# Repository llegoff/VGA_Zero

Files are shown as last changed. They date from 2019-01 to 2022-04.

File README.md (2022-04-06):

[:fr:](LISEZMOI.md) [:uk:](README.md)

# VGA_Zero
VGA interface for Raspberry Pi Zéro &amp; 2,3,B+

for pi400 see https://github.com/llegoff/Pi400VGA

buy rev3 on [ebay](https://www.ebay.fr/itm/154857982971) :package:

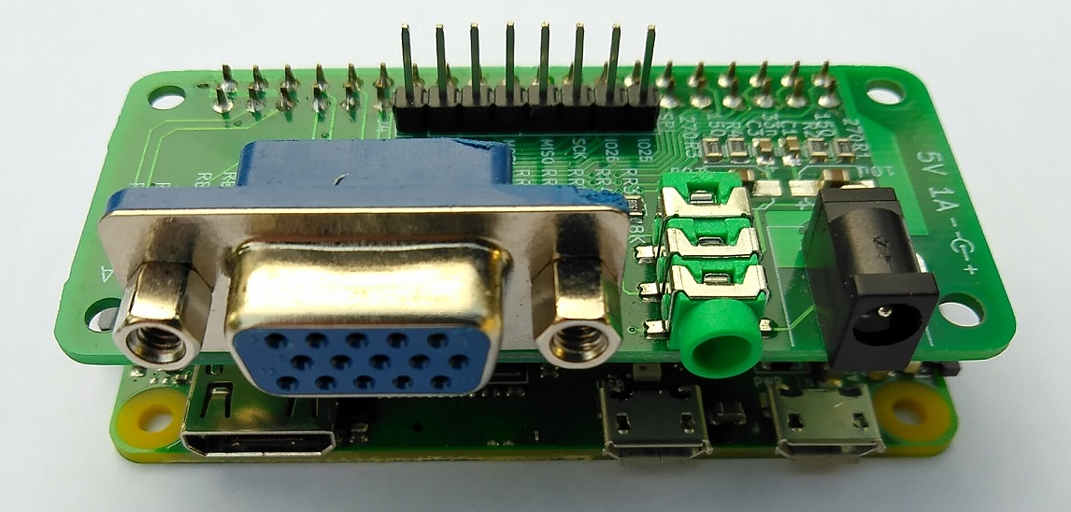
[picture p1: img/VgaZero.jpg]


### DPI (Display parallel Interface)
Like [VGA666](https://github.com/fenlogic/vga666), this pcb uses dpi interface (in mode 3 to free gpio 18 & 19)

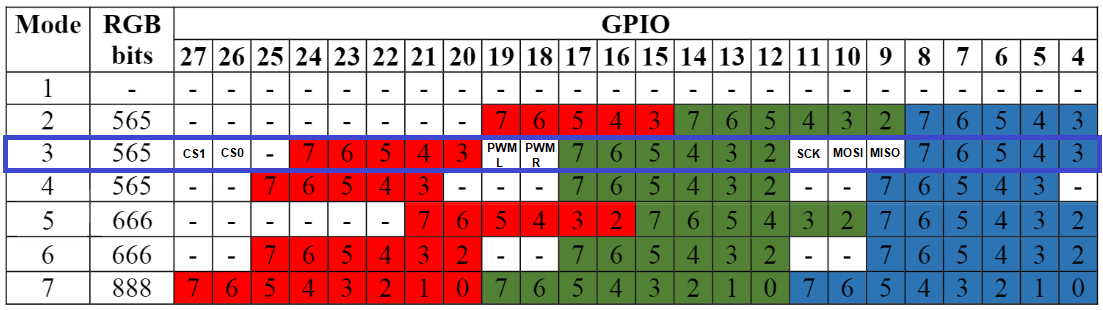
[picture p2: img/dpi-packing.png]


see https://www.raspberrypi.org/documentation/hardware/raspberrypi/dpi/README.md

only the necessary bits of the dpi are redirected to the 40-pin GPIO port, with the [vga565.dtbo](overlays/vga565.dtbo?raw=true) file loaded at startup

here is the code of the file:

    /dts-v1/;
    /plugin/;
    /{
    	compatible = "brcm,bcm2708";
    	// There is no VGA driver module, but we need a platform device
    	// node (that doesn't already use pinctrl) to hang the pinctrl
    	// reference on - leds will do
    	fragment@0 {
    		target = <&leds>;
    		__overlay__ {
    			pinctrl-names = "default";
    			pinctrl-0 = <&vga565_pins>;
    		};
	    };
    	fragment@1 {
    		target = <&gpio>;
    		__overlay__ {
    			vga565_pins: vga565_pins {
        			brcm,pins = <2 3 4 5 6 7 8 12 13 14 15 16 17 20 21 22 23 24>;
    				brcm,function = <6>; /* alt2 */
				    brcm,pull = <0>; /* no pull */
			    };
		    };
	    };
    };

/boot/config.txt
    
    # disable i2c, pin use by h-sync & v-sync
    dtparam=i2c_arm=off
    dtoverlay=vga565
    dpi_output_format=0x13
    enable_dpi_lcd=1
    display_default_lcd=1
    dpi_group=2
    dpi_mode=16
    #---------------- dpi_mode line ---------------------
    #---> 640x480 60hz    dpi_mode=4
    #---> 800x600 60hz    dpi_mode=9
    #---> 1024x768 60hz   dpi_mode=16
    #---> 1280x768 60hz   dpi_mode=23
    #---> 1280x800 60hz   dpi_mode=28
    #---> 1280x960 60hz   dpi_mode=32
    #---> 1280x1024 60hz  dpi_mode=35
    #---> 1360x768 60hz   dpi_mode=39
    #---> 1366x768 60hz   dpi_mode=81
    #---> 1400x1050 60hz  dpi_mode=42
    #---> 1440x900 60hz   dpi_mode=47
    #---> 1600x1200 60hz  dpi_mode=51
    #---> 1680x1050 60hz  dpi_mode=58
    #---> 1920x1080 60hz  dpi_mode=82
    #---> 1920x1200 60hz  dpi_mode=69
    #---> 1920x1440 60hz  dpi_mode=73

alternate config, no need dtbo file

    # replace dtoverlay=vc4-kms-v3d with
    dtoverlay=vc4-fkms-v3d
    # disable i2c, pin use by h-sync & v-sync
    dtparam=i2c_arm=off
    gpio=2-8,12-17,20-24=a2
    dpi_output_format=0x13
    enable_dpi_lcd=1
    display_default_lcd=1
    dpi_group=2
    dpi_mode=16
    #---------------- dpi_mode line ---------------------
    #---> 640x480 60hz    dpi_mode=4
    #---> 800x600 60hz    dpi_mode=9
    #---> 1024x768 60hz   dpi_mode=16
    #---> 1280x768 60hz   dpi_mode=23
    #---> 1280x800 60hz   dpi_mode=28
    #---> 1280x960 60hz   dpi_mode=32
    #---> 1280x1024 60hz  dpi_mode=35
    #---> 1360x768 60hz   dpi_mode=39
    #---> 1366x768 60hz   dpi_mode=81
    #---> 1400x1050 60hz  dpi_mode=42
    #---> 1440x900 60hz   dpi_mode=47
    #---> 1600x1200 60hz  dpi_mode=51
    #---> 1680x1050 60hz  dpi_mode=58
    #---> 1920x1080 60hz  dpi_mode=82
    #---> 1920x1200 60hz  dpi_mode=69
    #---> 1920x1440 60hz  dpi_mode=73

Configuration working with vc4-kms-v3d

    dtoverlay=vc4-kms-dpi-generic,rgb565-padhi
    dtparam=hactive=800,hfp=40,hsync=128,hbp=88
    dtparam=vactive=600,vfp=1,vsync=4,vbp=23
    dtparam=clock-frequency=40000000
    #   Resolution@freq  hactive hfp hsync  hbp vactive vfp vsync vbp  clock-frequency
    #VGA   640x480  @60   640     16   96    48   480    10   2    33    25175000
    #SVGA  800x600  @60   800     40  128    88   600     1   4    23    40000000
    #XGA  1024x768  @60  1024     24  136   160   768     3   6    29    65000000
    #VESA 1368x768  @60  1368     72  144   216   768     1   3    23    85860000
    #VESA 1280x800  @60  1280     64  136   200   800     1   3    24    83460000
    #VESA 1280x1024 @60  1280     48  112   248  1024     1   3    38   108000000
    #VESA 1400x1050 @60  1400     88  152   240  1050     1   3    33   122660000
    #VESA 1600x1200 @60  1600     64  192   304  1200     1   3    46   162000000
    #--- TV -----
    #244p (NTSC res)@60   320      4   30    46   240     4   5    14     6400000
    #288p (PAL res) @50   384     16   32    40   288     3   2    19     7363200
    #480i (NTSC res)@60   640     24   64   104   480     3   6    34    13054080
    #576i (PAL res) @50   768     24   72    88   576     6   5    38    14875000
    #480p           @60   640     24   96    48   480    11   2    32    25452000
    #720p           @60  1280    110   40   220   720     5   5    20    74250000
    #1080p          @60  1920     88   44   148  1080     4   5    36   148500000
    #more timming on http://tinyvga.com/vga-timing

### 15khz cathode ray screen

    # disable i2c, pin use by h-sync & v-sync
    dtparam=i2c_arm=off
    gpio=2-8,12-17,20-24=a2
    dpi_output_format=0x13
    enable_dpi_lcd=1
    display_default_lcd=1
    dpi_group=2
    dpi_mode=87
    #hdmi_timings=506 1 8 48 56 240 1 3 10 6 0 0 0 60 0 9600000 1
    #hdmi_timings=512 1 16 48 64 288 1 3 5 6 0 0 0 50 0 9600000 1
    # Custom 15kHz mode
    hdmi_timings=506 1 8 44 52 240 1 6 10 6 0 0 0 60 0 9600000 1
    #hdmi_timings=320 1 17 33 34 224 1 14 8 18 0 0 0 60 0 6400000 1
    #hdmi_timings=960 0 173 8 0 160 0 40 10 0 0 0 0 60 0 19200000 8
    #hdmi_timings=320 1 25 30 30 240 1 9 3 10 0 0 0 60 0 6400000 1
    #hdmi_timings=1920 1 52 208 260 240 1 6 10 6 0 0 0 60 0 38400000 1
    
for recalbox see https://recalbox.gitbook.io/tutorials/v/francais/video/crt/configurez-votre-ecran-cathodique-sur-le-bus-dpi-vga666-piscart-rgbpi

### Dual Screen (VGA + HDMI)

on the pi4 and pi400, the dual screen function is supported by the vc4 fkms v3d driver

    [pi4]
    # Enable DRM VC4 V3D driver on top of the dispmanx display stack
    dtoverlay=vc4-fkms-v3d
    max_framebuffers=2
    
for previous versions:

:warning: need raspbian buster

edit file /boot/config.txt  

at the end of the file, add line:

    [all]
    #dtoverlay=vc4-fkms-v3d
    max_framebuffers=2

edit file /usr/share/X11/xorg.conf.d/99-fbturbo.conf

     This is a minimal sample config file, which can be copied to
    # /etc/X11/xorg.conf in order to make the Xorg server pick up
    # and load xf86-video-fbturbo driver installed in the system.    
    #
    # When troubleshooting, check /var/log/Xorg.0.log for the debugging
    # output and error messages.
    #
    # Run "man fbturbo" to get additional information about the extra
    # configuration options for tuning the driver.
    
    #Section "Device"
    #        Identifier      "Allwinner A10/A13 FBDEV"
    #        Driver          "fbturbo"
    #        Option          "fbdev" "/dev/fb0"
    #        Option          "SwapbuffersWait" "true"
    #EndSection
    
    Section "Device"
    Identifier "Raspberry Pi HDMI"
    Driver "fbturbo"
    Option "fbdev" "/dev/fb0"
    Option "ShadowFB" "off"
    EndSection
    
    Section "Device"
    Identifier "Raspberry Pi DPI"
    Driver "fbturbo"
    Option "fbdev" "/dev/fb1"
    Option "ShadowFB" "off"
    EndSection
    
    Section "Monitor"
    Identifier "HDMI"
    EndSection

    Section "Monitor"
    Identifier "DPI"
    EndSection
    
    Section "Screen"
    Identifier "screen0"
    Device "Raspberry Pi HDMI"
    Monitor "HDMI"
    EndSection
    
    Section "Screen"
    Identifier "screen1"
    Device "Raspberry Pi DPI"
    Monitor "DPI"
    EndSection
    
    Section "ServerLayout"
    Identifier "default"
    Screen 0 "screen0" 0 0
    Screen 1 "screen1" RightOf "screen0"
    Option "Xinerama" "on"
    EndSection
### Remote Desktop MultiMonitor
install freeRDP

    sudo apt-get install freerdp2-x11

start freeRDP session
    
    xfreerdp /v:<computer name or IP> /u:<user> /d:<domain> /sound:sys:alsa /multimon

or

    xfreerdp /v:<computer name or IP> /u:<user> /d:<domain> /g:<gateway name or IP> /gu:<gateway user> /gd:<gateway domain> /sound:sys:alsa /multimon

### Audio Interface
audio interface is connected to gpio 18 & 19 (PWM)

see https://learn.adafruit.com/adding-basic-audio-ouput-to-raspberry-pi-zero/pi-zero-pwm-audio

/boot/config.txt

    # Enable audio for PiZero(loads snd_bcm2835)
    dtoverlay=pwm-2chan,pin=18,func=2,pin2=19,func2=2
    dtparam=audio=on

For Pi4 or Pi400 use audremap overlay

/boot/config.txt

    # Enable audio for PiZero(loads snd_bcm2835)
    dtoverlay=audremap,pins_18_19
    dtparam=audio=on

### SPI Interface
GPIO 9 , 10, 11 , 25, 26, 27 can be used as SPI , whit overlay spi0-cs, with CS redirection to gpio 26 & 27

/boot/config.txt

    # uncomment to use spi0 with cs0 & cs1 retirected on pin 26 & 27 
    dtparam=spi=on
    dtoverlay=spi0-cs,cs0_pin=26,cs1_pin=27

## Schematic
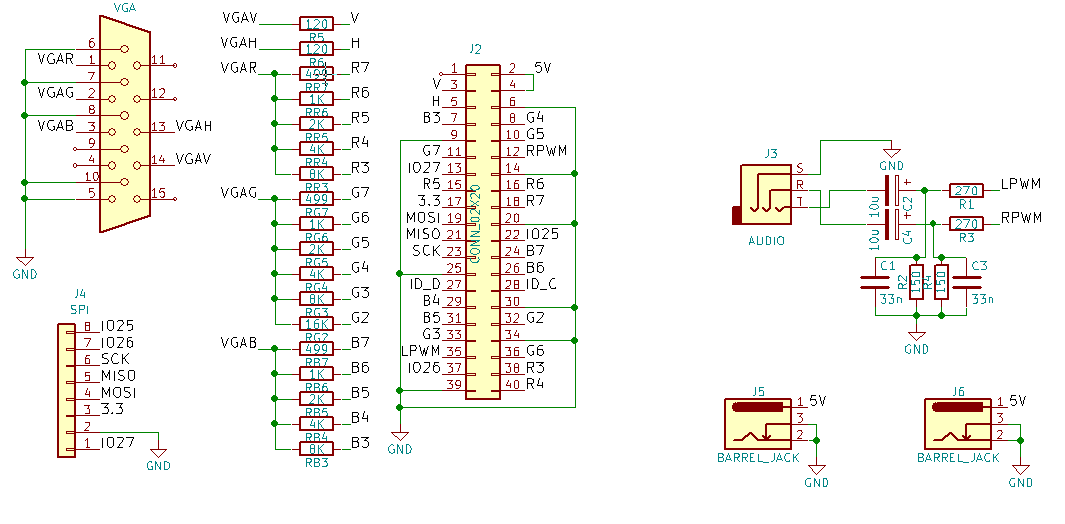
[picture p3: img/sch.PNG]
sch


## PCB
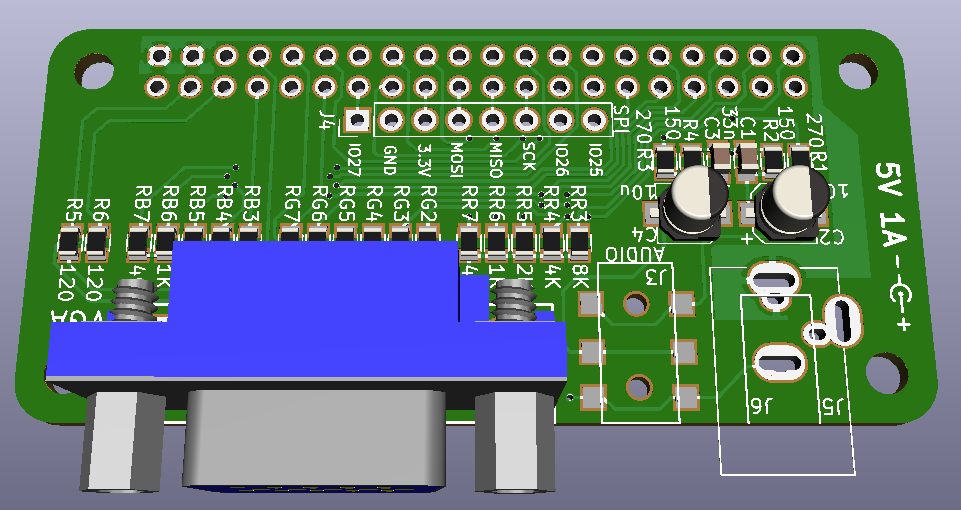
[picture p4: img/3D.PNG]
pcb


## Installation
Copy [vga565.dtbo](overlays/vga565.dtbo?raw=true) to /boot/overlays/
and copy content of [config-example.txt](overlays/config-example.txt?raw=true) to /boot/config.txt

## Révision
rev1
- bad vga footprint, hole too small

rev2
- change vga footprint
- move j3 & j5

rev3
- add GPIO25 to J4 connector
- add j6 DC 3.5x1.3 connector
- change to Kicad v5.0.2 lib

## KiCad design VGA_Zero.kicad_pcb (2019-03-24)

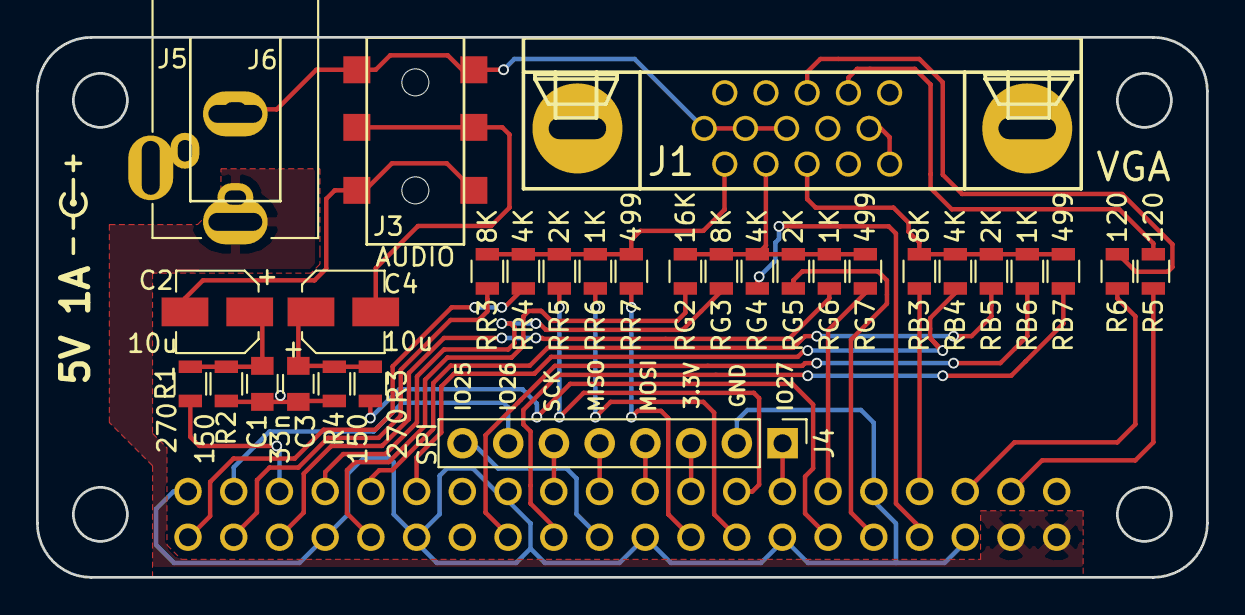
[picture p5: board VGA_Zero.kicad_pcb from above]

Board: 2 copper layers, 65.0 x 30.0 mm, 32 parts (0 on the bottom side), 38 nets.

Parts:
C1, C3: 33n; C_0805
C2, C4: 10u; CP_Elec_4x5.3
J1: VGA; DB_15F-VGA
J2: CONN_02X20; RaspberryPiZeroHAT
J3: AUDIO; jack3.5smd
J4: SPI; Pin_Header_Straight_1x08_Pitch2.54mm
J5: BARREL_JACK
J6: BARREL_JACK; DC002_3.5x1.1
R1, R3: 270; R_0805
R2, R4: 150; R_0805
R5, R6: 120; R_0805
RB3: 8K; R_0805
RB4: 4K; R_0805
RB5: 2K; R_0805
RB6: 1K; R_0805
RB7: 499; R_0805
RG2: 16K; R_0805
RG3: 8K; R_0805
RG4: 4K; R_0805
RG5: 2K; R_0805
RG6: 1K; R_0805
RG7: 499; R_0805
RR3: 8K; R_0805
RR4: 4K; R_0805
RR5: 2K; R_0805
RR6: 1K; R_0805
RR7: 499; R_0805

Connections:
/3.3: J2.17, J4.3
/5V: J2.2, J2.4, J5.1, J6.1
/B3: J2.7, RB3.1
/B4: J2.29, RB4.1
/B5: J2.31, RB5.1
/B6: J2.26, RB6.1
/B7: J2.24, RB7.1
/G2: J2.32, RG2.1
/G3: J2.33, RG3.1
/G4: J2.8, RG4.1
/G5: J2.10, RG5.1
/G6: J2.36, RG6.1
/G7: J2.11, RG7.1
/H: J2.5, R6.1
/IO25: J2.22, J4.8
/IO26: J2.37, J4.7
/IO27: J2.13, J4.1
/LPWM: J2.35, R1.1
/MISO: J2.21, J4.5
/MOSI: J2.19, J4.4
/R3: J2.38, RR3.1
/R4: J2.40, RR4.1
/R5: J2.15, RR5.1
/R6: J2.16, RR6.1
/R7: J2.18, RR7.1
/RPWM: J2.12, R3.1
/SCK: J2.23, J4.6
/V: J2.3, R5.1
/VGAB: J1.3, RB3.2, RB4.2, RB5.2, RB6.2, RB7.2
/VGAG: J1.2, RG2.2, RG3.2, RG4.2, RG5.2, RG6.2, RG7.2
/VGAH: J1.13, R6.2
/VGAR: J1.1, RR3.2, RR4.2, RR5.2, RR6.2, RR7.2
/VGAV: J1.14, R5.2
GND: C1.2, C3.2, J1.5, J1.6, J1.7, J1.8, J1.10, J2.6, J2.9, J2.14, J2.20, J2.25, J2.30, J2.34, J2.39, J3.S, J4.2, J5.2, J5.3, J6.2, J6.3, R2.1, R4.1
unnamed: C1.1, C2.1, R1.2, R2.2
unnamed: C2.2, J3.T
unnamed: C3.1, C4.1, R3.2, R4.2
unnamed: C4.2, J3.R

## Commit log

2017-09-08 rev1
    warning bad vga footprint
    [VGA_Zero.kicad_pcb, VGA_Zero.sch]
2019-02-06 Kicad v5.0.2 lib
2019-02-07 Kicad 5.0.2 lib
    [VGA_Zero.kicad_pcb]
